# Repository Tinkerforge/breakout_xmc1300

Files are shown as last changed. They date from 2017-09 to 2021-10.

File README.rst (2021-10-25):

XMC1300 Breakout
================

This repository contains the firmware source code and the hardware design
files. The documentation generator configs can be found at
https://github.com/Tinkerforge/generators

Repository Content
------------------

software/:
 * examples/: Examples for all supported languages
 * build/: Makefile and compiled files
 * src/: Source code of firmware
 * generate_makefile: Shell script to generate Makefile from cmake script

hardware/:
 * Contains kicad project files and additionally schematics as pdf

datasheets/:
 * Contains datasheets for sensors and complex ICs that are used

Hardware
--------

The hardware is designed with the open source EDA Suite KiCad
(http://www.kicad.org). Before you are able to open the files,
you have to install the Tinkerforge kicad-libraries
(https://github.com/Tinkerforge/kicad-libraries). You can either clone
them directly in hardware/ or clone them in a separate folder and
symlink them into hardware/
(ln -s kicad_path/kicad-libraries project_path/hardware). After that you
can open the .pro file in hardware/ with kicad and from there view and
modify the schematics and the PCB layout.

Software
--------

To compile the c code we recommend you to install the newest CodeSourcery arm
eabi gcc compiler
(http://www.codesourcery.com/sgpp/lite/arm/portal/subscription?@template=lite).
You also need to install bricklib (https://github.com/Tinkerforge/bricklib)
and brickletlib (https://github.com/Tinkerforge/brickletlib).
You can either clone them directly in software/src/ or clone them in a
separate folder and symlink them into software/src/
(ln -s bricklib_path/bricklib project_path/software/src/).

After that you can generate a Makefile from the cmake script with the
generate_makefile shell script (in software/) and build the firmware
by invoking make in software/build/. The firmware (.bin) can then be found
in software/build/ and uploaded with brickv (click button "Flashing"
on start screen).

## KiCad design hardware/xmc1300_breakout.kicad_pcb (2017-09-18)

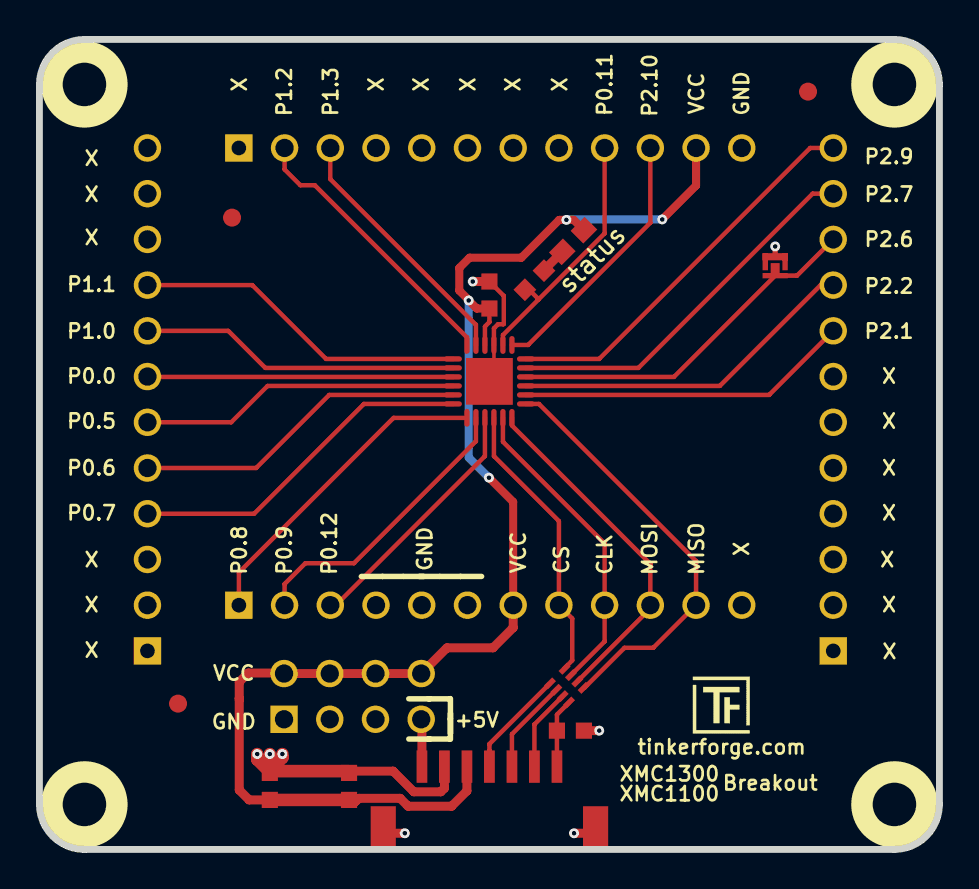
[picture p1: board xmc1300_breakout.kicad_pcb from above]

Board: 2 copper layers, 50.0 x 45.0 mm, 24 parts (0 on the bottom side), 30 nets.

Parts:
C1: 10uF; C0603F
C2: 1uF; C0603F
C3: 220pF; C0603F
C4: 100nF; C0603F
D3: blue; D0603E
Fiducial_Mark: VAL**; Fiducial_Mark
Fiducial_Mark#2, Fiducial_Mark#3: VAL**; Fiducial_Mark
P1: CON-SENSOR2
P2: BOOT; SolderJumper
P3, P4, P5, P6: CONN_01X12; pin_array_12
P7: CONN_02X04; pin_array_4x2
R1: 1k; R0603F
RP1: 82; 4X0402
U1: XMC1XXX24; QFN24-4x4mm-0.5mm
U2, U3, U4, U5: DRILL; DRILL_NP
VAL: CE_5mm
VAL#2: WEEE_7mm_back

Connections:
+5V: P1.1, P7.7
GND: C1.1, C2.1, C3.1, C4.2, P1.2, P1.EP, P2.1, P3.12, P5.5, P5.6, P7.1, P7.3, P7.5, U1.9, U1.EXP
unnamed: C3.2, P1.7, RP1.8
unnamed: D3.2, R1.2
unnamed: P1.4, RP1.5
unnamed: P1.5, RP1.6
unnamed: P1.6, RP1.7
Pin4: P4.9, U1.13
Pin5: P4.8, U1.14
Pin6: P4.7, U1.15
Pin7: P4.6, U1.16
Pin8: P4.5, U1.17
Pin9: P4.4, U1.18
Pin13: P5.1, U1.19
Pin14: P5.2, U1.20
Pin15: P5.3, U1.21
Pin32: P6.8, U1.2
Pin33: P6.9, U1.3
Pin34: P2.2, P6.10, U1.4
Pin35: P6.11, U1.5
Pin36: P6.12, U1.6
Pin39: P3.10, U1.7
Pin40: P3.9, R1.1, U1.8
Pin46: P3.3, U1.11
Pin47: P3.2, U1.12
S-CLK: P5.9, RP1.3, U1.23
S-CS: P5.8, RP1.4, U1.22
S-MISO: P5.11, RP1.1, U1.1
S-MOSI: P5.10, RP1.2, U1.24
VCC: C1.2, C2.2, C4.1, D3.1, P1.3, P3.11, P5.7, P7.2, P7.4, P7.6, P7.8, U1.10

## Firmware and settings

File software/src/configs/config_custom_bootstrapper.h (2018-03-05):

/* solid-state-relay-v2-bricklet
 * Copyright (C) 2017 Olaf Lüke <olaf@tinkerforge.com>
 *
 * config_custom_bootstrapper.h: XMC bootstrapper configurations for 
 *                               Solid State Relay V2 Bricklet
 *
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
 * You should have received a copy of the GNU Lesser General Public
 * License along with this library; if not, write to the
 * Free Software Foundation, Inc., 59 Temple Place - Suite 330,
 * Boston, MA 02111-1307, USA.
 */

#ifndef CONFIG_CUSTOM_BOOTSTRAPPER_H
#define CONFIG_CUSTOM_BOOTSTRAPPER_H

// TODO: CHECK ALL DEFINES!!!

#define BOOTSTRAPPER_STATUS_LED_PIN P2_11
#define BOOTSTRAPPER_USIC_CHANNEL   USIC0_CH0
#define BOOTSTRAPPER_PAGE_SIZE      256
#define BOOTSTRAPPER_FLASH_START    0x10001000

#define BOOTSTRAPPER_USIC           XMC_UART0_CH0
#define BOOTSTRAPPER_RX_PIN         P0_14
#define BOOTSTRAPPER_RX_INPUT       XMC_USIC_CH_INPUT_DX0
#define BOOTSTRAPPER_RX_SOURCE      0b000 // DX0A

#define BOOTSTRAPPER_TX_PIN         P0_15
#define BOOTSTRAPPER_TX_PIN_AF      (XMC_GPIO_MODE_OUTPUT_PUSH_PULL_ALT6 | P0_15_AF_U0C0_DOUT0)

#define BOOTSTRAPPER_BMI_WITH_CAN   0

#endif

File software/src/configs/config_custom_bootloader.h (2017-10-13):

/* solid-state-relay-v2-bricklet
 * Copyright (C) 2017 Olaf Lüke <olaf@tinkerforge.com>
 *
 * config_custom_bootloader.h: Bootloader configurations for 
 *                             Solid State Relay V2 Bricklet
 *
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
 * You should have received a copy of the GNU Lesser General Public
 * License along with this library; if not, write to the
 * Free Software Foundation, Inc., 59 Temple Place - Suite 330,
 * Boston, MA 02111-1307, USA.
 */

#ifndef CONFIG_CUSTOM_BOOTLOADER_H
#define CONFIG_CUSTOM_BOOTLOADER_H

#include "xmc_gpio.h"

// TODO: CHECK ALL DEFINES!!!

// --- Basic defines ---
#define BOOTLOADER_DEVICE_IDENTIFIER   296
#define BOOTLOADER_HW_VERSION_MAJOR    1
#define BOOTLOADER_HW_VERSION_MINOR    0
#define BOOTLOADER_HW_VERSION_REVISION 0

#define BOOTLOADER_STATUS_LED_PIN      P2_11
#define BOOTLOADER_BOOT_PAD_PIN        P2_6

#define BOOTLOADER_FLASH_EEPROM_SIZE   (4*256)
#define BOOTLOADER_FLASH_SIZE          (16*1024 - BOOTLOADER_FLASH_EEPROM_SIZE)

// --- SPITFP ---
#define SPITFP_USIC_CHANNEL         USIC0_CH0
#define SPITFP_USIC                 XMC_SPI0_CH0

#define SPITFP_SCLK_PIN             P0_14
#define SPITFP_SCLK_INPUT           XMC_USIC_CH_INPUT_DX1
#define SPITFP_SCLK_SOURCE          0b000 // DX1A

#define SPITFP_SELECT_PIN           P0_13
#define SPITFP_SELECT_INPUT         XMC_USIC_CH_INPUT_DX2
#define SPITFP_SELECT_SOURCE        0b101 // DX2F

#define SPITFP_MOSI_PIN             P0_15
#define SPITFP_MOSI_INPUT           XMC_USIC_CH_INPUT_DX0
#define SPITFP_MOSI_SOURCE          0b001 // DX0B

#define SPITFP_MISO_PIN             P2_0
#define SPITFP_MISO_PIN_AF          (XMC_GPIO_MODE_OUTPUT_PUSH_PULL_ALT6 | P2_0_AF_U0C0_DOUT0)

#define SPITFP_RECEIVE_BUFFER_SIZE  1024
#define SPITFP_RECEIVE_BUFFER_MASK  (SPITFP_RECEIVE_BUFFER_SIZE-1) // If size is power of 2

#define SPITFP_SERVICE_REQUEST_RX   0
#define SPITFP_SERVICE_REQUEST_TX   1

#define SPITFP_IRQ_RX               9
#define SPITFP_IRQ_RX_PRIORITY      2
#define SPITFP_IRQ_TX               10
#define SPITFP_IRQ_TX_PRIORITY      3

#define SPITFP_TX_DATA_POINTER      16
#define SPITFP_TX_SIZE              XMC_USIC_CH_FIFO_SIZE_16WORDS
#define SPITFP_TX_LIMIT             8

#define SPITFP_RX_DATA_POINTER      0
#define SPITFP_RX_SIZE              XMC_USIC_CH_FIFO_SIZE_16WORDS
#define SPITFP_RX_LIMIT             0

// --- BOOTLOADER FUNCTIONS ---

// define bootloader functions to put them into the BootloaderFunctions struct
// These functions are in the bootloader code and can be used from the firmware

#define BOOTLOADER_FUNCTION_SPITFP_TICK
#define BOOTLOADER_FUNCTION_SEND_ACK_AND_MESSAGE
#define BOOTLOADER_FUNCTION_SPITFP_IS_SEND_POSSIBLE
#define BOOTLOADER_FUNCTION_AEABI_IDIV
#define BOOTLOADER_FUNCTION_AEABI_UIDIV
#define BOOTLOADER_FUNCTION_AEABI_IDIVMOD
#define BOOTLOADER_FUNCTION_AEABI_UIDIVMOD
#define BOOTLOADER_FUNCTION_GET_UID
#define BOOTLOADER_FUNCTION_READ_EEPROM_PAGE
#define BOOTLOADER_FUNCTION_WRITE_EEPROM_PAGE

#endif

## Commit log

2017-09-13 Add schematic
    [xmc1300_breakout.sch]
2017-09-13 Add PCB
    [xmc1300_breakout.kicad_pcb]
2017-09-14 Fix BootPad & add status marking for status LED
    [xmc1300_breakout.kicad_pcb]
2017-09-18 Fix GND path under MCU
    [xmc1300_breakout.kicad_pcb]
2017-10-13 Add initial stub implementation
    [cmake_config_custom.txt]
2021-10-25 Update KiCad link
    https://www.kicad.org/blog/2021/10/Avoid-links-to-former-kicad-domain/

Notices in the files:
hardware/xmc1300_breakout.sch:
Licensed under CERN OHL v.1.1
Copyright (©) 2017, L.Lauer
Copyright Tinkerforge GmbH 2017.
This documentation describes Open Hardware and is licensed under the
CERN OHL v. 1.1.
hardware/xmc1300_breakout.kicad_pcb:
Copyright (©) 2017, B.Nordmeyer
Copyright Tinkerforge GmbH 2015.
